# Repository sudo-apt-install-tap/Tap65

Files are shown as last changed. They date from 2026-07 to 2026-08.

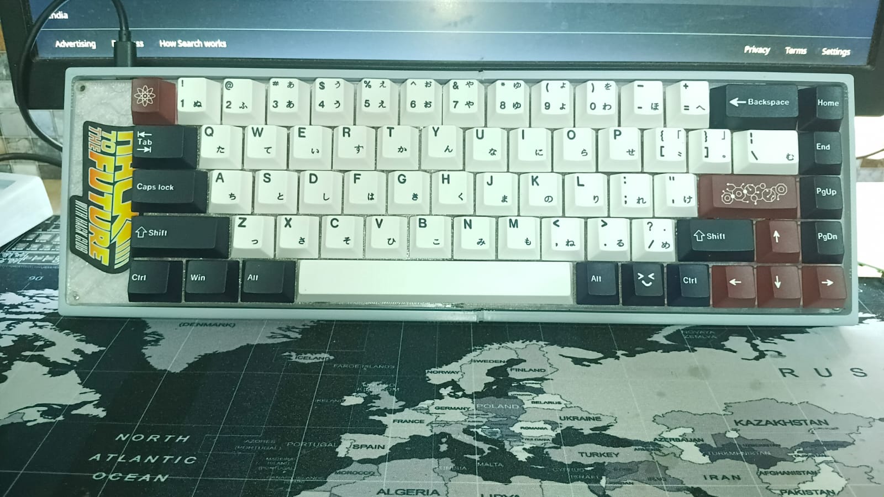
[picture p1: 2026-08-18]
images/Finished Build.jpeg

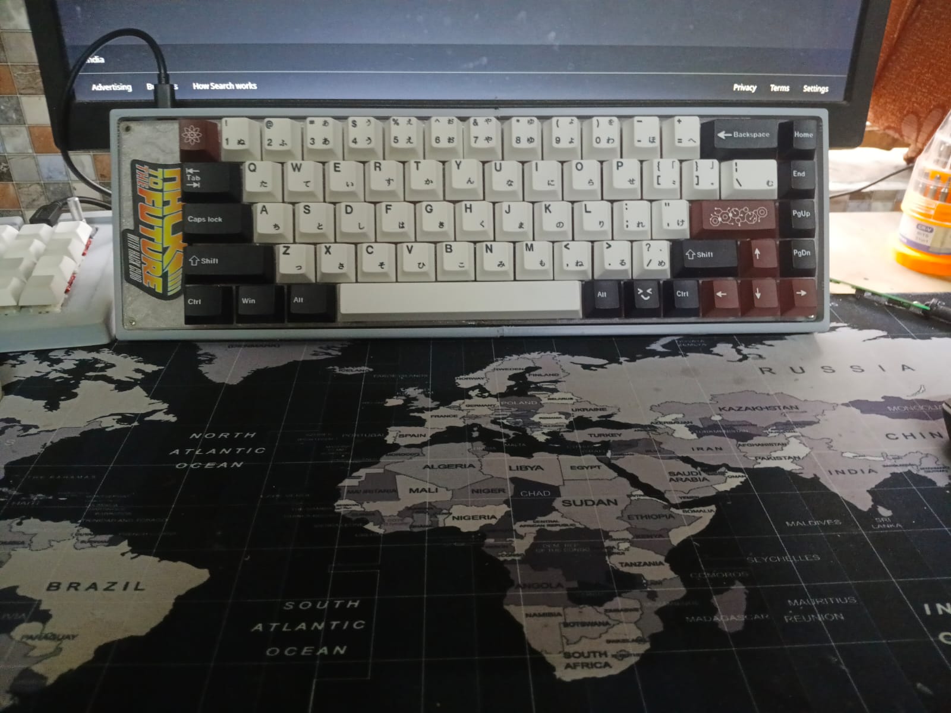
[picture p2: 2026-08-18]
images/Build Pt2.jpeg

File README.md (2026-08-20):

<center>

# Tap65: 68-Key Mechanical Keyboard

A fully custom 68-key mechanical keyboard designed from the ground up, including the PCB, case, firmware, and assembly. This project was built to learn the complete keyboard design process while creating a functional keyboard tailored to my own preferences.

Funded With The Help Of JLCPCB and HackClub's YSWS Keeb

## Features

- Custom PCB designed from scratch
- Hot-swappable MX-compatible switches
- QMK firmware support
- Screw-in stabilizers
- 3D printed two-piece tray mount case
- 7° typing angle for improved ergonomics
- Per Key RGB

## Why I Built It

I've always been interested in mechanical keyboards and wanted to understand how they work beyond simply assembling pre-made kits. Instead of buying an existing keyboard, I decided to design every major component myself.

This project gave me the opportunity to learn PCB design, CAD modelling, firmware configuration, manufacturing, soldering, and the overall engineering process behind modern custom keyboards.

## Design Process

The project began by selecting a 68-key layout that balances compactness with everyday usability. I then designed the PCB in KiCad, routed all the traces, and added support for hot-swap sockets and USB-C connectivity. After the electronics were complete I designed a simple tray mount in Onshape. The case is made out of two PLA printed pieces and includes a 7° typing angle for a more comfortable typing experience. Because of small bed size I will have to print them in pieces.

Finally, the keyboard is programmed using kmk firmware.

## Components

- Custom PCB
- Raspberry Pi Pico
- MX-compatible switches
- Durock Clear Screw-In Stabilizers V2
- Hot-swap sockets
- USB-C connector
- 3D printed PLA case
- Keycaps
- SK6812 mini-e

## Challenges

Some of the biggest challenges included:

- Learning PCB routing and keyboard matrix design
- Neopixel wiring
- Designing a printable case that was both strong and easy to assemble
- Ensuring all mounting points aligned correctly
- Managing component sourcing and costs

## What I Learned

Through this project I learned:

- PCB design using KiCad
- CAD modelling in Onshape
- Mechanical keyboard architecture
- KMK scripting
- Case design

## Files:
PCB production ready files availabe in [Production](/fabrication). CAD files availabe on OnShape [Tap65](https://cad.onshape.com/documents/8f869f2a44712437e4702e46/w/78ecf35c97da350371a517a7/e/15a686cf102c39b24f8e8911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)

## Images and Renders!

### Matrix Schematic
<br><br>

### Neopixel
<br><br>

### MCU - Raspberry Pi PICO
<br><br>

### PCB
<br><br>

### PCB Render - 3D Viewer

#### Front
<br><br>

#### Back
<br><br>

### OnShape Render

#### Case
image-removebg-preview <br><br>

#### Plate
 <br><br>

### PCB
 <br><br>

### Assembly
 <br><br>

## Sketch
 <br><br>

## Build Images And Videos:

#### So I did something very stupid, the neopixles, sk6812 mini-e and normal sk6812 have the same looking symbols in KiCAD, BUT the one and only difference is that the pin numbers, according to the datasheet for the mini-e variant it doesn't match, so the connections and traces are faulty. This leads to a failure in the basic pcb which can not be fixed/patched in anyway after production. But still the keyboard works well enough. And I think that was enough yapping, so, heres some pics!!

https://github.com/user-attachments/assets/bb973c62-ae0b-457b-894d-c5b485d0465b

https://github.com/user-attachments/assets/a8adbe74-d3f2-401a-ac2d-03d99a9797de

Build Pt2

Finished Build

Finished(withStabs)

clone soldered on

## Bill of Materials (BOM)

| SI No. | Name | Notes | Quantity | Price Per Unit (₹) | Total (₹) | Running Total (₹) | Price/Unit (USD) | Total (USD) | Running Total (USD) | Link |
| -----: | --- | --- | ---: | ---: | ---: | ---: | ---: | ---: | ---: | --- |
| 1 | Keygeek x MZ Y1 Keyboard Switch (Pack of 10) | MX compatible switches | 7 | 300 | 2100 | 2100 | 3.16 | 22.11 | 22.11 | stackskb.com/store/keygeek-y1-keyboard-switch/ |
| 2 | PCB (JLC Sponsored) | Sponsored PCB from JLCPCB | 1 | 200 | 200 | 2300 | 2.11 | 2.11 | 24.21 | jlcpcb.com |
| 3 | Durock Clear Screw-In Stabilizers V2 | Screw-in stabs | 1 | 1600 | 1600 | 3900 | 16.84 | 16.84 | 41.05 | stackskb.com/store/durock-clear-screw-in-stabilizers-v2/ |
| 4 | Gateron Hotswap Sockets | Hotswap sockets | 70 | 10 | 700 | 4600 | 0.11 | 7.37 | 48.42 | stackskb.com/store/gateron-hotswap-sockets/ |
| 5 | 1N4148 SOD-123 SMD Diode (Pack of 10) | N-key rollover | 7 | 20 | 140 | 4740 | 0.21 | 1.47 | 49.89 | stackskb.com/store/1n4148-sod-123-smd-diode/ |
| 6 | Ykyio Keycap Set | Keycaps | 1 | 1,599 | 1599 | 6339 | 16.83 | 16.83 | 66.73 | meckeys.com/shop/accessories/keyboard-accessories/keycaps/ykyio-keycap-set/ |
| 7 | Pico | MCU | 1 | 450 | 450 | 6789 | 4.74 | 4.74 | 71.46 | makerbazar.in/products/luatos-usb-c-raspberry-pi-pico-development-board-based-on-rp2040-microcontroller |
| 8 | Heat Set Insert | M3 | 7 | 15 | 105 | 6894 | 0.16 | 1.11 | 72.57 | makerbazar.in/products/brass-heat-set-threaded-round-female-insert-nut |
| 9 | Screw Philips | Pack of 10 | 1 | 25 | 25 | 6919 | 0.26 | 0.26 | 72.83 | makerbazar.in/products/philips-head-nuts-bolts-set-silver-plated-pack-of-10 |
| 10 | Neopixels (SK6812 Mini-E) | LCSC | 100 | 19 | 1900 | 8819 | 0.20 | 20.00 | 92.83 | lcsc.com/product-detail/Light-Emitting-Diodes-LED_OPSCO-Optoelectronics-SK6812MINI-E_C5149201.html |

## Credits

This project was made possible through open-source hardware and firmware resources, along with support from the mechanical keyboard community. Special thanks to Hack Club and JLCPCB for helping make the project possible.

</center>

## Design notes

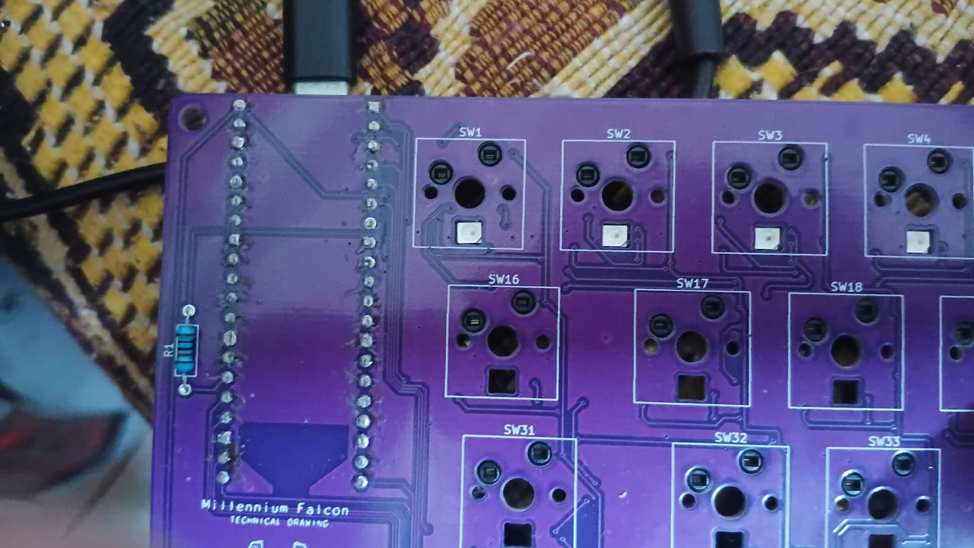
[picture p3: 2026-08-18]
images/Front shot of sk6812 mini-e.jpeg

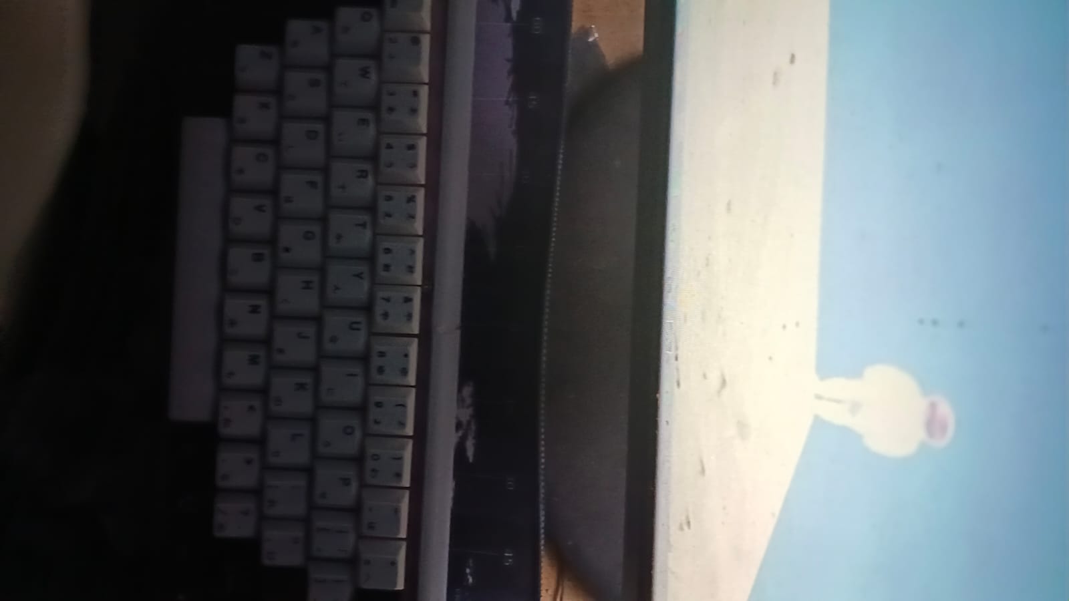
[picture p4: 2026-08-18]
images/Keyboard after lubing.jpeg

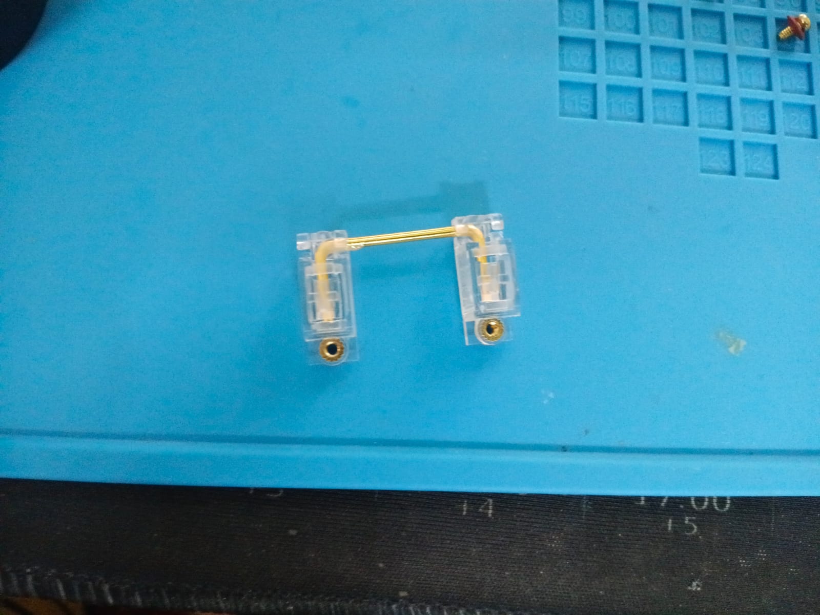
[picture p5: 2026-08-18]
images/Lubed Stabs.jpeg

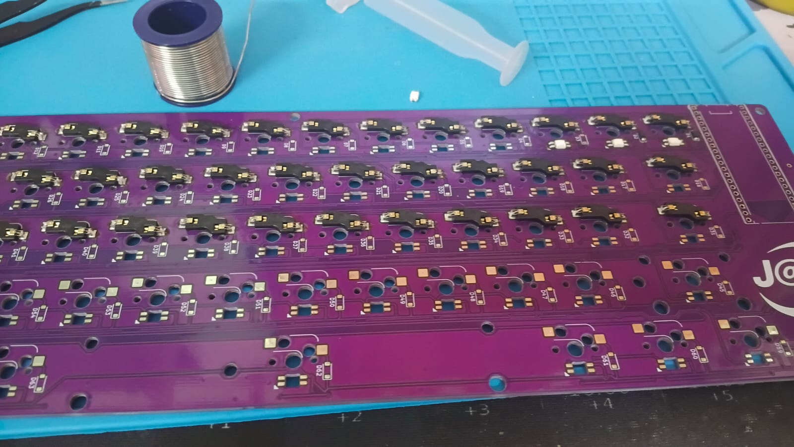
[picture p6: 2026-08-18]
images/Half Finished PCB.jpeg

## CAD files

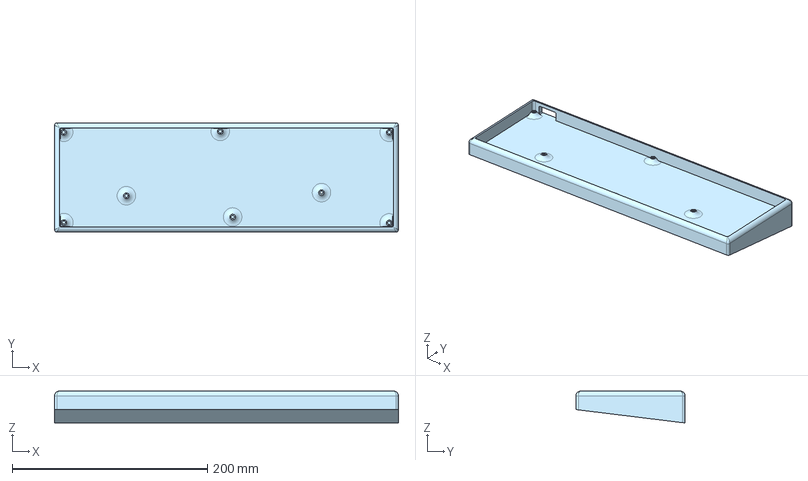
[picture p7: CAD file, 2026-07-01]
CAD/Case/Case.step
352.8 x 111.9 x 32.7 mm

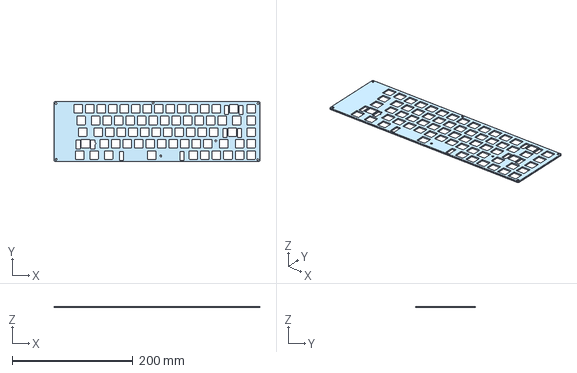
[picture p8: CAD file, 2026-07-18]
CAD/PLATE/plate.step
340.8 x 100.0 x 2.00 mm

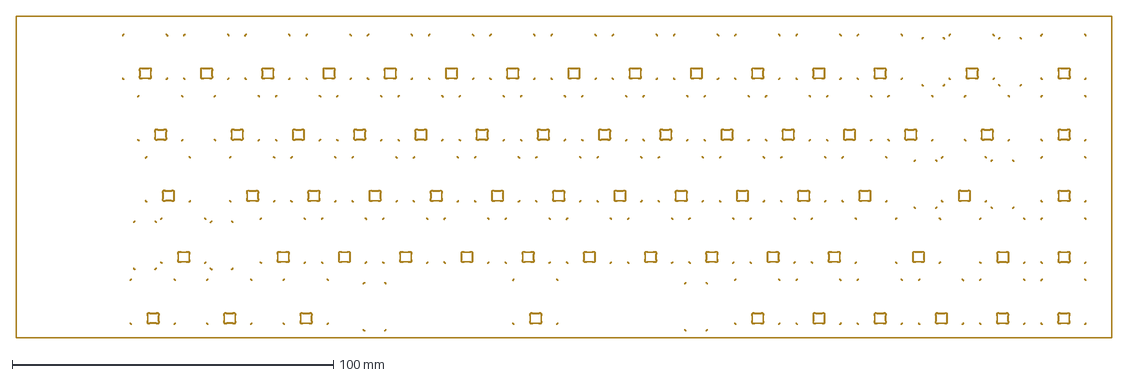
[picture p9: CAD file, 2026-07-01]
fabrication/pcb-Edge_Cuts.dxf
340.8 x 100.0 mm

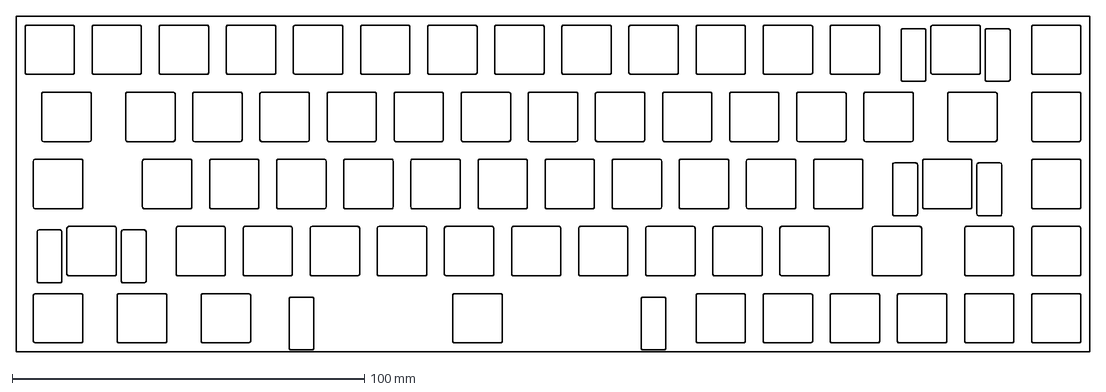
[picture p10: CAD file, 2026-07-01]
images/plate-2026-06-29T15_20_20.652Z.dxf
304.8 x 95.2 mm

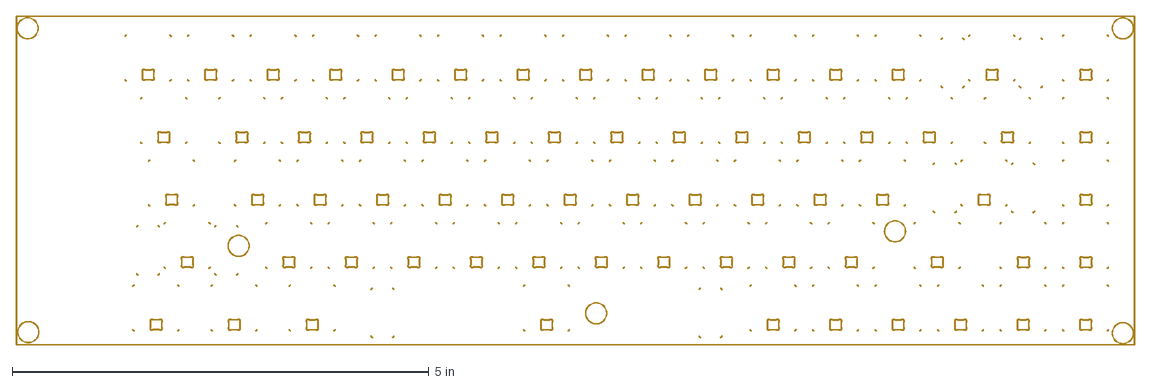
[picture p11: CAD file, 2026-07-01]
CAD/PLATE/pcb-Edge_Cuts.dxf
13.4 x 3.94 in

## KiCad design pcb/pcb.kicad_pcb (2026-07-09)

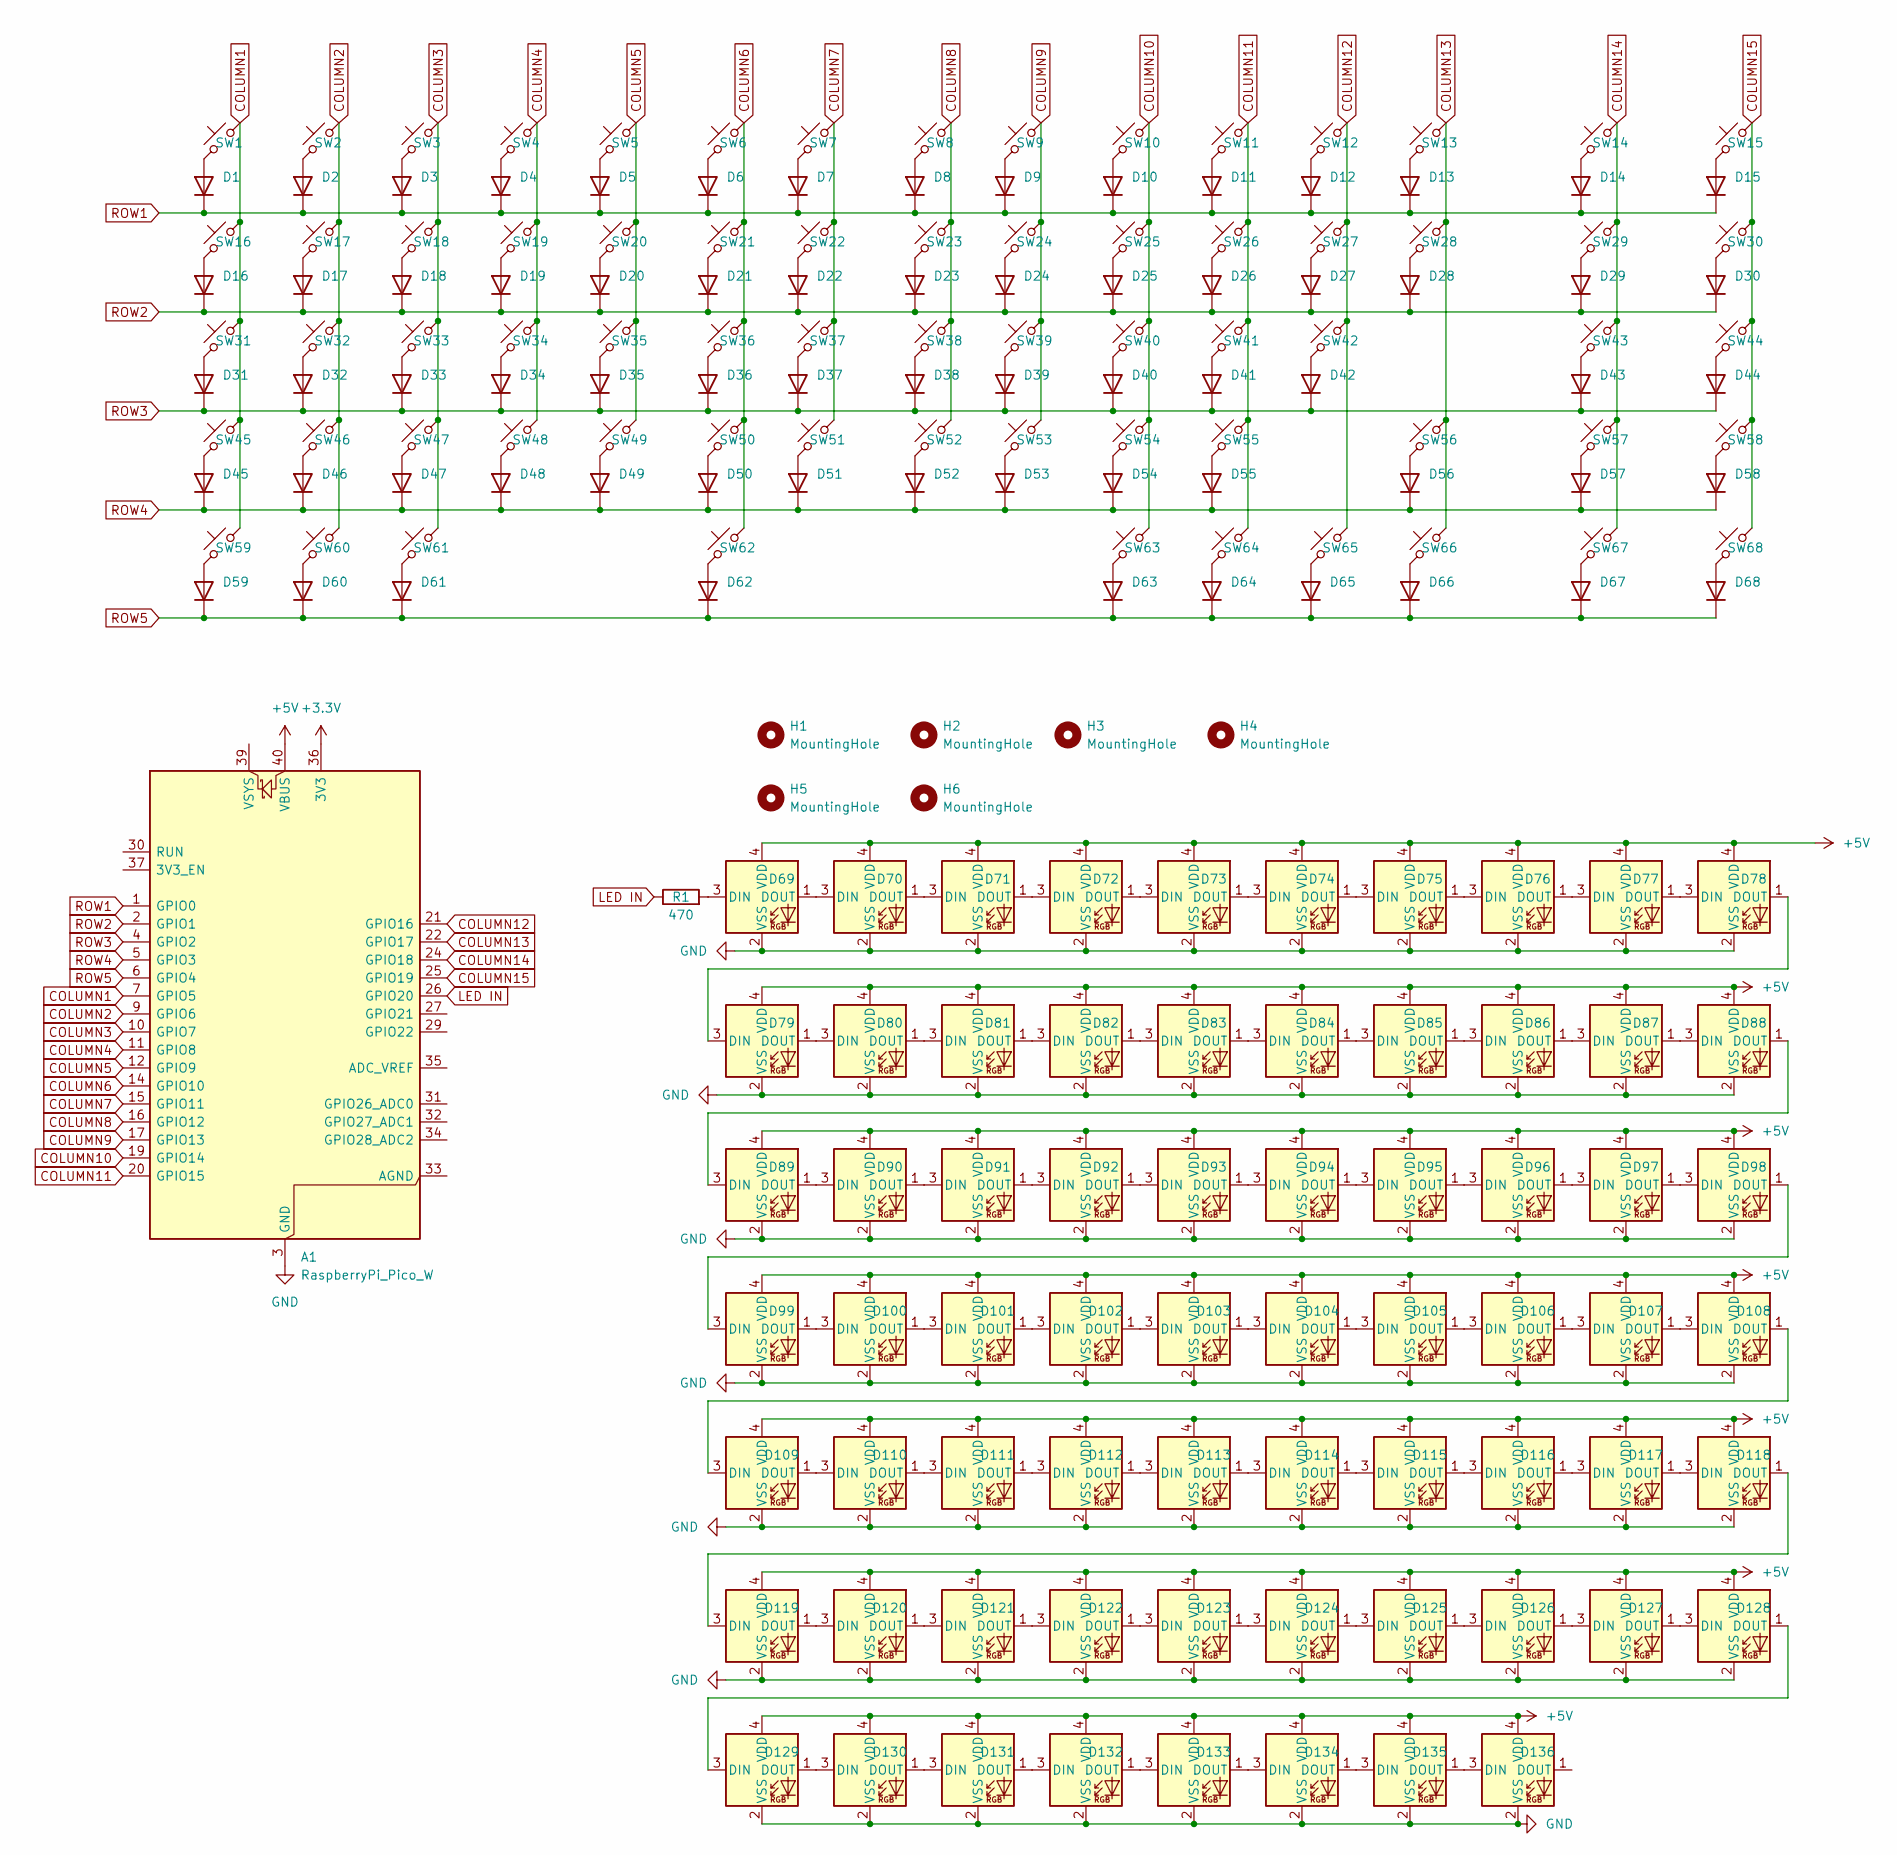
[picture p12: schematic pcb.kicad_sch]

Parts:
A1: RaspberryPi_Pico_W; RaspberryPi_Pico_Common_THT
D1, D2, D3, D4, D5, D6, D7, D8, D9, D10, D11, D12, D13, D14, D15, D16, D17, D18, D19, D20, D21, D22, D23, D24, D25, D26, D27, D28, D29, D30, D31, D32, D33, D34, D35, D36, D37, D38, D39, D40, D41, D42, D43, D44, D45, D46, D47, D48, D49, D50, D51, D52, D53, D54, D55, D56, D57, D58, D59, D60, D61, D62, D63, D64, D65, D66, D67, D68: 1N4148WT; D_SOD-123
D69, D70, D71, D72, D73, D74, D75, D76, D77, D78, D79, D80, D81, D82, D83, D84, D85, D86, D87, D88, D89, D90, D91, D92, D93, D94, D95, D96, D97, D98, D99, D100, D101, D102, D103, D104, D105, D106, D107, D108, D109, D110, D111, D112, D113, D114, D115, D116, D117, D118, D119, D120, D121, D122, D123, D124, D125, D126, D127, D128, D129, D130, D131, D132, D133, D134, D135, D136: SK6812MINI; MX_SK6812MINI-E
H1, H2, H3, H4, H5, H6: MountingHole; MountingHole_3.2mm_M3
R1: 470; R_Axial_DIN0614_L14.3mm_D5.7mm_P20.32mm_Horizontal
SW1, SW2, SW3, SW4, SW5, SW6, SW7, SW8, SW9, SW10, SW11, SW12, SW13, SW15, SW17, SW18, SW19, SW20, SW21, SW22, SW23, SW24, SW25, SW26, SW27, SW28, SW30, SW32, SW33, SW34, SW35, SW36, SW37, SW38, SW39, SW40, SW41, SW42, SW44, SW46, SW47, SW48, SW49, SW50, SW51, SW52, SW53, SW54, SW55, SW57, SW58, SW63, SW64, SW65, SW66, SW67, SW68: SW_Push_45deg; SW_Hotswap_Kailh_MX_1.00u
SW14: SW_Push_45deg; SW_Hotswap_Kailh_MX_Plated_2.00u
SW16, SW29: SW_Push_45deg; SW_Hotswap_Kailh_MX_Plated_1.50u
SW31, SW56: SW_Push_45deg; SW_Hotswap_Kailh_MX_Plated_1.75u
SW43, SW45: SW_Push_45deg; SW_Hotswap_Kailh_MX_Plated_2.25u
SW59, SW60, SW61: SW_Push_45deg; SW_Hotswap_Kailh_MX_Plated_1.25u
SW62: SW_Push_45deg; SW_Hotswap_Kailh_MX_Plated_6.25u

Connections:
+3.3V: A1.36 (3V3)
+5V: A1.40 (VBUS), D69.4 (VDD), D70.4 (VDD), D71.4 (VDD), D72.4 (VDD), D73.4 (VDD), D74.4 (VDD), D75.4 (VDD), D76.4 (VDD), D77.4 (VDD), D78.4 (VDD), D79.4 (VDD), D80.4 (VDD), D81.4 (VDD), D82.4 (VDD), D83.4 (VDD), D84.4 (VDD), D85.4 (VDD), D86.4 (VDD), D87.4 (VDD), D88.4 (VDD), D89.4 (VDD), D90.4 (VDD), D91.4 (VDD), D92.4 (VDD), D93.4 (VDD), D94.4 (VDD), D95.4 (VDD), D96.4 (VDD), D97.4 (VDD), D98.4 (VDD), D99.4 (VDD), D100.4 (VDD), D101.4 (VDD), D102.4 (VDD), D103.4 (VDD), D104.4 (VDD), D105.4 (VDD), D106.4 (VDD), D107.4 (VDD), D108.4 (VDD), D109.4 (VDD), D110.4 (VDD), D111.4 (VDD), D112.4 (VDD), D113.4 (VDD), D114.4 (VDD), D115.4 (VDD), D116.4 (VDD), D117.4 (VDD), D118.4 (VDD), D119.4 (VDD), D120.4 (VDD), D121.4 (VDD), D122.4 (VDD), D123.4 (VDD), D124.4 (VDD), D125.4 (VDD), D126.4 (VDD), D127.4 (VDD), D128.4 (VDD), D129.4 (VDD), D130.4 (VDD), D131.4 (VDD), D132.4 (VDD), D133.4 (VDD), D134.4 (VDD), D135.4 (VDD), D136.4 (VDD)
COLUMN1: A1.7 (GPIO5), SW1.2, SW16.2, SW31.2, SW45.2, SW59.2
COLUMN2: A1.9 (GPIO6), SW2.2, SW17.2, SW32.2, SW46.2, SW60.2
COLUMN3: A1.10 (GPIO7), SW3.2, SW18.2, SW33.2, SW47.2, SW61.2
COLUMN4: A1.11 (GPIO8), SW4.2, SW19.2, SW34.2, SW48.2
COLUMN5: A1.12 (GPIO9), SW5.2, SW20.2, SW35.2, SW49.2
COLUMN6: A1.14 (GPIO10), SW6.2, SW21.2, SW36.2, SW50.2, SW62.2
COLUMN7: A1.15 (GPIO11), SW7.2, SW22.2, SW37.2, SW51.2
COLUMN8: A1.16 (GPIO12), SW8.2, SW23.2, SW38.2, SW52.2
COLUMN9: A1.17 (GPIO13), SW9.2, SW24.2, SW39.2, SW53.2
COLUMN10: A1.19 (GPIO14), SW10.2, SW25.2, SW40.2, SW54.2, SW63.2
COLUMN11: A1.20 (GPIO15), SW11.2, SW26.2, SW41.2, SW55.2, SW64.2
COLUMN12: A1.21 (GPIO16), SW12.2, SW27.2, SW42.2, SW65.2
COLUMN13: A1.22 (GPIO17), SW13.2, SW28.2, SW56.2, SW66.2
COLUMN14: A1.24 (GPIO18), SW14.2, SW29.2, SW43.2, SW57.2, SW67.2
COLUMN15: A1.25 (GPIO19), SW15.2, SW30.2, SW44.2, SW58.2, SW68.2
GND: A1.3 (GND), A1.8 (GND), A1.13 (GND), A1.18 (GND), A1.23 (GND), A1.28 (GND), A1.38 (GND), D69.2 (VSS), D70.2 (VSS), D71.2 (VSS), D72.2 (VSS), D73.2 (VSS), D74.2 (VSS), D75.2 (VSS), D76.2 (VSS), D77.2 (VSS), D78.2 (VSS), D79.2 (VSS), D80.2 (VSS), D81.2 (VSS), D82.2 (VSS), D83.2 (VSS), D84.2 (VSS), D85.2 (VSS), D86.2 (VSS), D87.2 (VSS), D88.2 (VSS), D89.2 (VSS), D90.2 (VSS), D91.2 (VSS), D92.2 (VSS), D93.2 (VSS), D94.2 (VSS), D95.2 (VSS), D96.2 (VSS), D97.2 (VSS), D98.2 (VSS), D99.2 (VSS), D100.2 (VSS), D101.2 (VSS), D102.2 (VSS), D103.2 (VSS), D104.2 (VSS), D105.2 (VSS), D106.2 (VSS), D107.2 (VSS), D108.2 (VSS), D109.2 (VSS), D110.2 (VSS), D111.2 (VSS), D112.2 (VSS), D113.2 (VSS), D114.2 (VSS), D115.2 (VSS), D116.2 (VSS), D117.2 (VSS), D118.2 (VSS), D119.2 (VSS), D120.2 (VSS), D121.2 (VSS), D122.2 (VSS), D123.2 (VSS), D124.2 (VSS), D125.2 (VSS), D126.2 (VSS), D127.2 (VSS), D128.2 (VSS), D129.2 (VSS), D130.2 (VSS), D131.2 (VSS), D132.2 (VSS), D133.2 (VSS), D134.2 (VSS), D135.2 (VSS), D136.2 (VSS)
LED IN: A1.26 (GPIO20), R1.1
unnamed: D1.2 (A), SW1.1
unnamed: D2.2 (A), SW2.1
unnamed: D3.2 (A), SW3.1
unnamed: D4.2 (A), SW4.1
unnamed: D5.2 (A), SW5.1
unnamed: D6.2 (A), SW6.1
unnamed: D7.2 (A), SW7.1
unnamed: D8.2 (A), SW8.1
unnamed: D9.2 (A), SW9.1
unnamed: D10.2 (A), SW10.1
unnamed: D11.2 (A), SW11.1
unnamed: D12.2 (A), SW12.1
unnamed: D13.2 (A), SW13.1
unnamed: D14.2 (A), SW14.1
unnamed: D15.2 (A), SW15.1
unnamed: D16.2 (A), SW16.1
unnamed: D17.2 (A), SW17.1
unnamed: D18.2 (A), SW18.1
unnamed: D19.2 (A), SW19.1
unnamed: D20.2 (A), SW20.1
unnamed: D21.2 (A), SW21.1
unnamed: D22.2 (A), SW22.1
unnamed: D23.2 (A), SW23.1
unnamed: D24.2 (A), SW24.1
unnamed: D25.2 (A), SW25.1
unnamed: D26.2 (A), SW26.1
unnamed: D27.2 (A), SW27.1
unnamed: D28.2 (A), SW28.1
unnamed: D29.2 (A), SW29.1
unnamed: D30.2 (A), SW30.1
unnamed: D31.2 (A), SW31.1
unnamed: D32.2 (A), SW32.1
unnamed: D33.2 (A), SW33.1
unnamed: D34.2 (A), SW34.1
unnamed: D35.2 (A), SW35.1
unnamed: D36.2 (A), SW36.1
unnamed: D37.2 (A), SW37.1
unnamed: D38.2 (A), SW38.1
unnamed: D39.2 (A), SW39.1
unnamed: D40.2 (A), SW40.1
unnamed: D41.2 (A), SW41.1
unnamed: D42.2 (A), SW42.1
unnamed: D43.2 (A), SW43.1
unnamed: D44.2 (A), SW44.1
unnamed: D45.2 (A), SW45.1
unnamed: D46.2 (A), SW46.1
unnamed: D47.2 (A), SW47.1
unnamed: D48.2 (A), SW48.1
unnamed: D49.2 (A), SW49.1
unnamed: D50.2 (A), SW50.1
unnamed: D51.2 (A), SW51.1
unnamed: D52.2 (A), SW52.1
unnamed: D53.2 (A), SW53.1
unnamed: D54.2 (A), SW54.1
unnamed: D55.2 (A), SW55.1
unnamed: D56.2 (A), SW56.1
unnamed: D57.2 (A), SW57.1
unnamed: D58.2 (A), SW58.1
unnamed: D59.2 (A), SW59.1
unnamed: D60.2 (A), SW60.1
unnamed: D61.2 (A), SW61.1
unnamed: D62.2 (A), SW62.1
unnamed: D63.2 (A), SW63.1
unnamed: D64.2 (A), SW64.1
unnamed: D65.2 (A), SW65.1
unnamed: D66.2 (A), SW66.1
unnamed: D67.2 (A), SW67.1
unnamed: D68.2 (A), SW68.1
unnamed: D69.3 (DIN), R1.2
unnamed: D69.1 (DOUT), D70.3 (DIN)
unnamed: D70.1 (DOUT), D71.3 (DIN)
unnamed: D71.1 (DOUT), D72.3 (DIN)
unnamed: D72.1 (DOUT), D73.3 (DIN)
unnamed: D73.1 (DOUT), D74.3 (DIN)
unnamed: D74.1 (DOUT), D75.3 (DIN)
unnamed: D75.1 (DOUT), D76.3 (DIN)
unnamed: D76.1 (DOUT), D77.3 (DIN)
unnamed: D77.1 (DOUT), D78.3 (DIN)
unnamed: D78.1 (DOUT), D79.3 (DIN)
unnamed: D79.1 (DOUT), D80.3 (DIN)
unnamed: D80.1 (DOUT), D81.3 (DIN)
unnamed: D81.1 (DOUT), D82.3 (DIN)
unnamed: D82.1 (DOUT), D83.3 (DIN)
unnamed: D83.1 (DOUT), D84.3 (DIN)
unnamed: D84.1 (DOUT), D85.3 (DIN)
unnamed: D85.1 (DOUT), D86.3 (DIN)
unnamed: D86.1 (DOUT), D87.3 (DIN)
unnamed: D87.1 (DOUT), D88.3 (DIN)
unnamed: D88.1 (DOUT), D89.3 (DIN)
unnamed: D89.1 (DOUT), D90.3 (DIN)
unnamed: D90.1 (DOUT), D91.3 (DIN)
unnamed: D91.1 (DOUT), D92.3 (DIN)
unnamed: D92.1 (DOUT), D93.3 (DIN)
unnamed: D93.1 (DOUT), D94.3 (DIN)
unnamed: D94.1 (DOUT), D95.3 (DIN)
unnamed: D95.1 (DOUT), D96.3 (DIN)
unnamed: D96.1 (DOUT), D97.3 (DIN)
unnamed: D97.1 (DOUT), D98.3 (DIN)
unnamed: D98.1 (DOUT), D99.3 (DIN)
unnamed: D99.1 (DOUT), D100.3 (DIN)
unnamed: D100.1 (DOUT), D101.3 (DIN)
unnamed: D101.1 (DOUT), D102.3 (DIN)
unnamed: D102.1 (DOUT), D103.3 (DIN)
unnamed: D103.1 (DOUT), D104.3 (DIN)
unnamed: D104.1 (DOUT), D105.3 (DIN)
unnamed: D105.1 (DOUT), D106.3 (DIN)
unnamed: D106.1 (DOUT), D107.3 (DIN)
unnamed: D107.1 (DOUT), D108.3 (DIN)
unnamed: D108.1 (DOUT), D109.3 (DIN)
unnamed: D109.1 (DOUT), D110.3 (DIN)
unnamed: D110.1 (DOUT), D111.3 (DIN)
unnamed: D111.1 (DOUT), D112.3 (DIN)
unnamed: D112.1 (DOUT), D113.3 (DIN)
unnamed: D113.1 (DOUT), D114.3 (DIN)
unnamed: D114.1 (DOUT), D115.3 (DIN)
unnamed: D115.1 (DOUT), D116.3 (DIN)
unnamed: D116.1 (DOUT), D117.3 (DIN)
unnamed: D117.1 (DOUT), D118.3 (DIN)
unnamed: D118.1 (DOUT), D119.3 (DIN)
unnamed: D119.1 (DOUT), D120.3 (DIN)
unnamed: D120.1 (DOUT), D121.3 (DIN)
unnamed: D121.1 (DOUT), D122.3 (DIN)
unnamed: D122.1 (DOUT), D123.3 (DIN)
unnamed: D123.1 (DOUT), D124.3 (DIN)
unnamed: D124.1 (DOUT), D125.3 (DIN)
unnamed: D125.1 (DOUT), D126.3 (DIN)
unnamed: D126.1 (DOUT), D127.3 (DIN)
unnamed: D127.1 (DOUT), D128.3 (DIN)
unnamed: D128.1 (DOUT), D129.3 (DIN)
unnamed: D129.1 (DOUT), D130.3 (DIN)
unnamed: D130.1 (DOUT), D131.3 (DIN)
unnamed: D131.1 (DOUT), D132.3 (DIN)
unnamed: D132.1 (DOUT), D133.3 (DIN)
unnamed: D133.1 (DOUT), D134.3 (DIN)
unnamed: D134.1 (DOUT), D135.3 (DIN)
unnamed: D135.1 (DOUT), D136.3 (DIN)
ROW1: A1.1 (GPIO0), D1.1 (K), D2.1 (K), D3.1 (K), D4.1 (K), D5.1 (K), D6.1 (K), D7.1 (K), D8.1 (K), D9.1 (K), D10.1 (K), D11.1 (K), D12.1 (K), D13.1 (K), D14.1 (K), D15.1 (K)
ROW2: A1.2 (GPIO1), D16.1 (K), D17.1 (K), D18.1 (K), D19.1 (K), D20.1 (K), D21.1 (K), D22.1 (K), D23.1 (K), D24.1 (K), D25.1 (K), D26.1 (K), D27.1 (K), D28.1 (K), D29.1 (K), D30.1 (K)
ROW3: A1.4 (GPIO2), D31.1 (K), D32.1 (K), D33.1 (K), D34.1 (K), D35.1 (K), D36.1 (K), D37.1 (K), D38.1 (K), D39.1 (K), D40.1 (K), D41.1 (K), D42.1 (K), D43.1 (K), D44.1 (K)
ROW4: A1.5 (GPIO3), D45.1 (K), D46.1 (K), D47.1 (K), D48.1 (K), D49.1 (K), D50.1 (K), D51.1 (K), D52.1 (K), D53.1 (K), D54.1 (K), D55.1 (K), D56.1 (K), D57.1 (K), D58.1 (K)
ROW5: A1.6 (GPIO4), D59.1 (K), D60.1 (K), D61.1 (K), D62.1 (K), D63.1 (K), D64.1 (K), D65.1 (K), D66.1 (K), D67.1 (K), D68.1 (K)

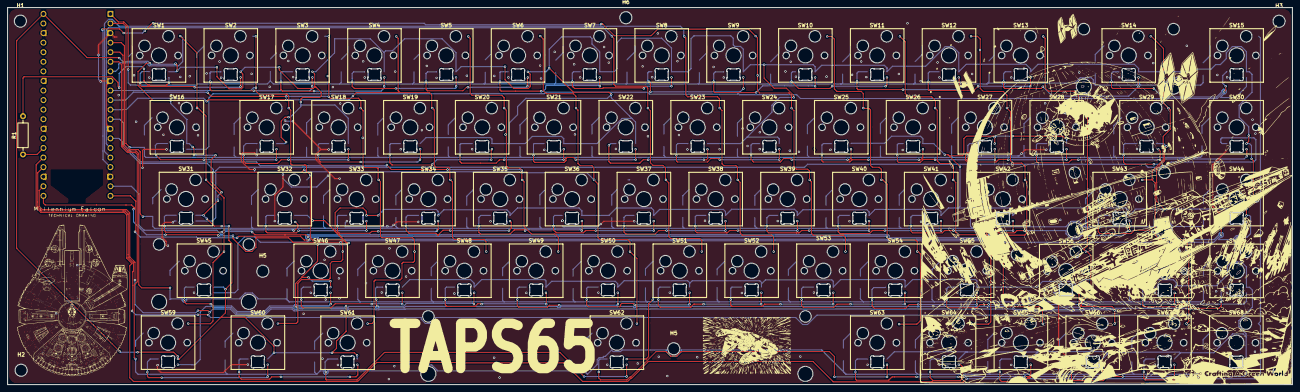
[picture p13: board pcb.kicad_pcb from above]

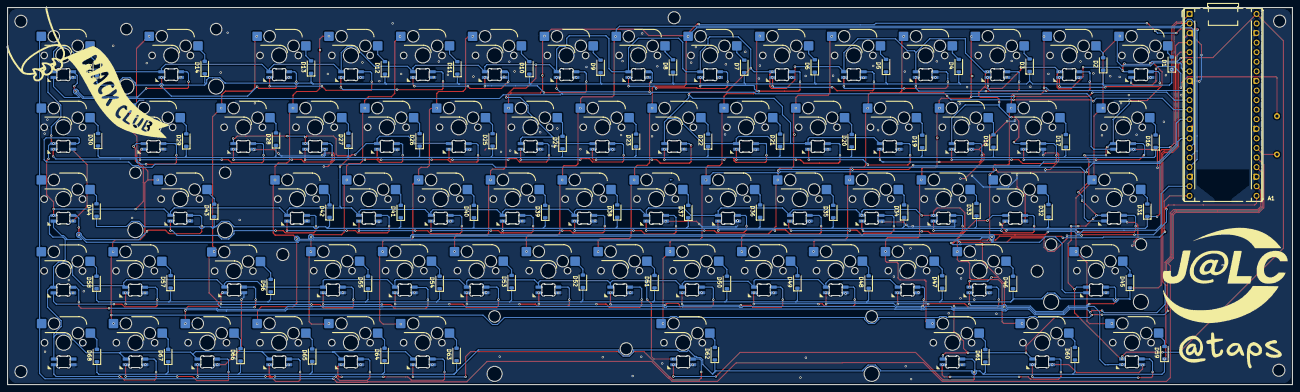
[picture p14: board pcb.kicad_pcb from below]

Board: 2 copper layers, 340.8 x 100.0 mm, 215 parts (70 on the bottom side), 159 nets.

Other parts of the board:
*: LOGO
H5#2, H5#3: MountingHole; MountingHole_3.2mm_M3

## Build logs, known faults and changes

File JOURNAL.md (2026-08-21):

---
title: "Tap65"
author: "Tap"
description: "A simple 68 key based layout!"
created_at: "2026-05-17"
---

# July 16: Got all the parts and test mounted stabs

Today I got all the PCB, keycaps and the switches, diodes and other stuff like stabilizers. The PCB was sponsored  by JLCPCB and i got DHL to deliver it so it was super duper fast. The keycaps and keyboard components were ordered from some local shops so it was very fast too!

heres some pic:

PCBs DAY1
Keycaps
PCB Stabalizer Fit

**Total time spent: 30m**

# 17 July: Soldered the hotswap sockets and some neopixles!

So soldering was very mind numbing and tedious, I did take a long time to solder all of them. I also soldered all the hotswap sockets but only a few neopixles in because i just wanted to test it. 

cool shot
Initial Neopixles
Half Finished PCB

> Half soldered sockets

Finished PCB
Soldering

**Total time spent: 6h**

# 18 July: Got the rubber feet + more images

So I got the rubber feet(they use this in furniture and shit) but it does give grip to stuff regardless so, I used it. Also I took another picture!

PCB
grips

**Total time spent: 30m**

# 19 July: Soldered the clone pico

I used a clone RPi pico instead of a standard one because the standard one uses a usb-b port. So I turned my head to the widely available pico clones on the market. I eventually got one from makerbazzar for cheaper than the original one.

clone soldered on

**Total time spent: 30m**

# 20 July: Debugged the neopixles.

So I did something very stupid, the neopixles, sk6812 mini-e and normal sk6812 have the same looking symbols in KiCAD, BUT the one and only difference is that the pin numbers, according to the datasheet for the mini-e variant it doesn't match, so the connections and traces are faulty. This leads to a failure in the basic pcb which can not be fixed/patched in anyway after production. But still the keyboard works well enough. This took me longer than it should've to figure it out . And I think that was enough yapping, so, heres some pics!!

Finished(withStabs)
Closeup shot of neopixels

**Total time spent: 2h 30m**

# 25 July: assembled the board

So I assembled the board, I just had to melt the two pieces of keyboard together. The heat set inserts were inserted by using a tweezers and a soldering iron. Then I just had to screw it into the case.

Build Pt2
Finished Build

**Total time spent: 3h**

# 26 July: Lubed the stabilizers!

I just used a rabbit hair brush no 1 to brush some krytox 2O5g into the housing and the wire to do make it sound better. So yeah that's about it lubing is pretty easy to be honest just takes a while and had to open and close it which tbh takes a bit of time.

Lubed Stabs
Keyboard after lubing
https://github.com/user-attachments/assets/0e627ef8-ceec-4c1e-9f21-f2216cf7b69a

**Total time spent: 1h**

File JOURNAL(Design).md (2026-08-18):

---
title: "Tap65"
author: "Tap"
description: "A simple 68 key based layout!"
created_at: "2026-05-17"
---

# May 17: Worked on the new pico based schematic and did the PCB layout!

So I did work on the schematic and the some of the pcb layout for the keyboard. I ended up scraping the old stm32 based embedded design.








into this

**Total time spent: 4hour**

# May 18: Finished the layout!

So I put the neopixles and the diodes in the place! It was monotonus but i liked doing it!!

Also the SK6812 Mini are really fricking expensive!








**Total time spent: 1.5hour**

# May 19: Neopixeles! Again!!

So I think I messed something up during the schematic phase and when i went to connect neopixles in a chain, Well the chain wasnt present, it was gone!

I decided to again make a new chain, this forced me to delete and start the routing from ground up again!

This time i did it properly and my routing is also much more cleaner, so I guess it should work properly.

Also I found a listing of the neopixels @ $17 for 200!



I will have to start routing the neopixels again but never the less its great!



**Total time spent: 3h**

# May 19: Finished PCB Routing!

Finished the full layout and routing! So it took FOREVER but I finally finished it and i used a hatched ground fill cuz why not!!





Will work on the art/silkscreen the next time!




**Total time spent: 4.5h**

# June 19: Added stabalizers and changed other stuff!

So I Added stabalizers as I did not want to use plate mounted ones because they tend to suck. Also i removed the hatched paturn and did a full GND pour, this makes it much more heavier and will probly make it feel pretty premium. Also as this is a 68 key layout I will be using a standard tray mount as it is much easier to design and opporate than a gasket mount. Did not go plateless as that wouldve made it more fragile. Anyways looks pretty good, will move on to case design the next day and yeah we will be done!

![image](https://github.com/user-attachments/assets/d9337de5-0cd0-451c-8f7c-92222b012bb2" />

![image](https://github.com/user-attachments/assets/452edccd-a6e3-44a7-af94-e941d1c5f72b" />

![image](https://github.com/user-attachments/assets/c220d1da-27cd-4909-875c-2eee7fe110d6" />

![image](https://github.com/user-attachments/assets/8d150a7d-dae7-4e11-9229-790d00debb39" />

![image](https://github.com/user-attachments/assets/de928ac4-1ee6-4eb2-9295-9bba2961d62c" />



**Total time spent: 1h**

# June 19: Added stabalizers and changed other stuff!

So today I finally got around to designing the case in Onshape!! I decided to keep it pretty simple and went with a standard 2 piece PLA tray mount case since the PCB was already designed around tray mounting. I also added a 7° typing angle because flat keyboards just don't feel that great to type on.I also filleted the edges around the plate so it doesn't look like a giant brick anymore lol. It honestly made the whole thing look much cleaner than before. Surprisingly I did not have to any major issues! Anyways the case is basically done now! Next thing I'll be working on is the firmware, and after that hopefully I'll be able to get a prototype made!!

![image](https://github.com/user-attachments/assets/19169598-c03d-49da-bbef-be4b6f581756" />
![image](https://github.com/user-attachments/assets/724045fb-e096-4512-8686-6f1963e7329c" />
![image](https://github.com/user-attachments/assets/7eddb9a4-db3f-448d-a123-49751fe3a66d" />
![image](https://github.com/user-attachments/assets/eaaf7925-9af5-44d9-977c-6b78e82492d5" />
![image](https://github.com/user-attachments/assets/9e8b4d8a-e3ff-4ccf-9b2e-bc140cf3d125" />

**Total time spent: 2h**

# July 1: Finished Firmware!

Today I started working on the KMK firmware for the keyboard. I set up the project structure, created the base 68-key keymap, and added a function layer with navigation and function keys. It took a bit of trial and error to understand how KMK handles layers and matrix scanning, but I eventually got a solid starting point. I also cleaned up the Git repository after accidentally committing some generated CAD files that were far too large for GitHub. With the firmware project now set up, the next step is to test the matrix on the actual PCB and begin adding features like RGB lighting and any other quality-of-life improvements.



**Total time spent: 1h 30m**

# July 2: Wrote The Readme!

Today I wrote a proper README for the project, documenting the keyboard's features, design process, bill of materials, and what I learned while building it. I also went back into the CAD model and fixed a few alignment issues between the case, plate, and PCB to make sure everything lines up correctly before manufacturing.

Finished look!




**Total time spent: 1h**

# July 16: Got all the parts and test mounted stabs

Today I got all the PCB, keycaps and the switches, diodes and other stuff like stabilizers. The PCB was sponsored  by JLCPCB and i got DHL to deliver it so it was super duper fast. The keycaps and keyboard components were ordered from some local shops so it was very fast too!

heres some pic:

PCBs DAY1
Keycaps
PCB Stabalizer Fit

**Total time spent: 30m**

# 17 July: Soldered the hotswap sockets and some neopixles!

So soldering was very mind numbing and tedious, I did take a long time to solder all of them. I also soldered all the hotswap sockets but only a few neopixles in because i just wanted to test it. 

cool shot
Initial Neopixles
Half Finished PCB

> Half soldered sockets

Finished PCB
Soldering

**Total time spent: 6h**

# 18 July: Got the rubber feet + more images

So I got the rubber feet(they use this in furniture and shit) but it does give grip to stuff regardless so, I used it. Also I took another picture!

PCB
grips

**Total time spent: 30m**

# 19 July: Soldered the clone pico

I used a clone RPi pico instead of a standard one because the standard one uses a usb-b port. So I turned my head to the widely available pico clones on the market. I eventually got one from makerbazzar for cheaper than the original one.

clone soldered on

**Total time spent: 30m**

# 20 July: Debugged the neopixles.

So I did something very stupid, the neopixles, sk6812 mini-e and normal sk6812 have the same looking symbols in KiCAD, BUT the one and only difference is that the pin numbers, according to the datasheet for the mini-e variant it doesn't match, so the connections and traces are faulty. This leads to a failure in the basic pcb which can not be fixed/patched in anyway after production. But still the keyboard works well enough. This took me longer than it should've to figure it out . And I think that was enough yapping, so, heres some pics!!

Finished(withStabs)
Closeup shot of neopixels

**Total time spent: 2h 30m**

# 25 July: assembled the board

So I assembled the board, I just had to melt the two pieces of keyboard together. The heat set inserts were inserted by using a tweezers and a soldering iron. Then I just had to screw it into the case.

Build Pt2
Finished Build

**Total time spent: 3h**

# 26 July: Lubed the stabilizers!

I just used a rabbit hair brush no 1 to brush some krytox 2O5g into the housing and the wire to do make it sound better. So yeah that's about it lubing is pretty easy to be honest just takes a while and had to open and close it which tbh takes a bit of time.

Lubed Stabs
Keyboard after lubing
https://github.com/user-attachments/assets/0e627ef8-ceec-4c1e-9f21-f2216cf7b69a

**Total time spent: 1h**

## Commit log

2026-01-16 Added Images - Finished Routing - Added silkscreen
    [pcb.kicad_pcb, pcb.kicad_sch]
2026-01-16 Update README with additional PCB images
    Added additional images of PCB front and back to the README.
2026-01-16 Rerouted - New Layout
    [pcb.kicad_pcb]
2026-01-23 Updated Images
    [pcb-Edge_Cuts.dxf, pcb.kicad_pcb]
2026-06-19 Update journal with stabilizer addition and design changes
    Added stabilizers and changed design elements for improved weight and feel. Updated layout to standard tray mount for easier operation.
2026-06-19 Added Stab holes to the PCB
2026-07-01 Added CAD Files And Basic KMK firmware
    [Case.step, pcb-Edge_Cuts.dxf, pcb.kicad_pcb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]
2026-07-02 Fixed Fab files
    [pcb-B_Adhesive.gbr, pcb-B_Courtyard.gbr, pcb-B_Cu.gbr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]
2026-07-02 Fix formatting and enhance BOM details in README
    Updated the README.md to correct formatting issues and improve clarity in the Bill of Materials section.
2026-07-09 Fixed DRC issues
    [pcb-B_Adhesive.gbr, pcb-B_Courtyard.gbr, pcb-B_Cu.gbr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]
2026-08-18 Added media
    [pcb.kicad_sch]
2026-08-20 Fixed BOM.CSV & BOM.XLSX
    [BOM.xlsx]
2026-08-21 Made a separate journal for build and design stagesgit pull
